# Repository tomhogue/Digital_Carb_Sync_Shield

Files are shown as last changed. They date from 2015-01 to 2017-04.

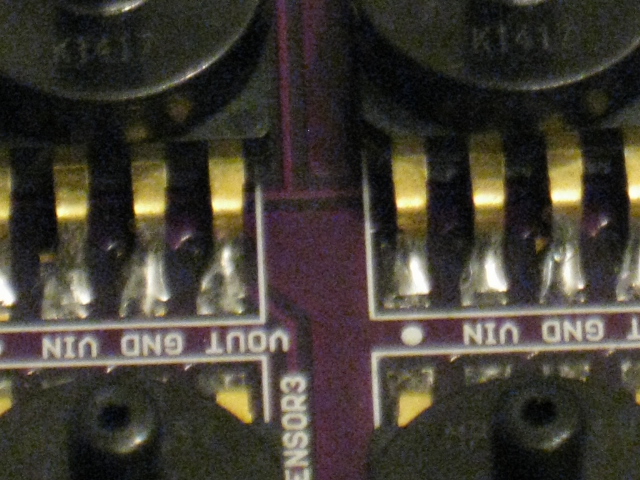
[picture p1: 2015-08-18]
CarbSync_CD_2015July/Pictures/hand solder results.JPG

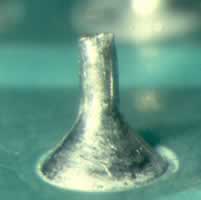
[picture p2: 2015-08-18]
CarbSync_CD_2015July/Pictures/good solder joint looks similar to this.jpg

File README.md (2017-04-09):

Digital Carb Sync Shield
========================

For the latest version and organization visit https://digitalcarbsync.com

Motorcycle carburetor synchronization. Analog sensors. LCD display. Easy to build. Wiki.

This repository is for the Digital Carb Sync Shield project. The shield is designed for the Arduino UNO R3
and other compatible boards.

The software is licensed under the MIT model.
The hardware is licensed using Open Hardware License.

The shield reads up to 6 vacuum pressure sensors on A0-5 and displays running peaks.

There is a calibration step to average the analog inputs. This is to compensate for build quality issues.

###Bill of Materials#

Some PCB boards may be available to GitHub collaborators.

Partial BOM sourced at Digi-Key. Shop around.

###More information and history at#

http://www.venturerider.org/forum/showthread.php?90191-New-digital-carb-sync-board

and its evolution from old auto parts

http://www.venturerider.org/forum/showthread.php?73158-Built-a-digital-carb-sync

and for Honda Valkyrie riders

http://www.valkyrieforum.com/bbs/index.php/topic,73795.0.html
http://www.valkyrieforum.com/bbs/index.php/topic,74909.0.html

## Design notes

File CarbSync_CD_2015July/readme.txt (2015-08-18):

Please read all the instructions in the CarbSync_Info folder before you begin.

There are useful pictures in the Pix folder.

The info folder includes the bill of materials, and helpful alternatives when ordering 
from the web.

The XLoader folder contains the MS-Windows program to load the software onto the board.
The software hex files are in the same folder.

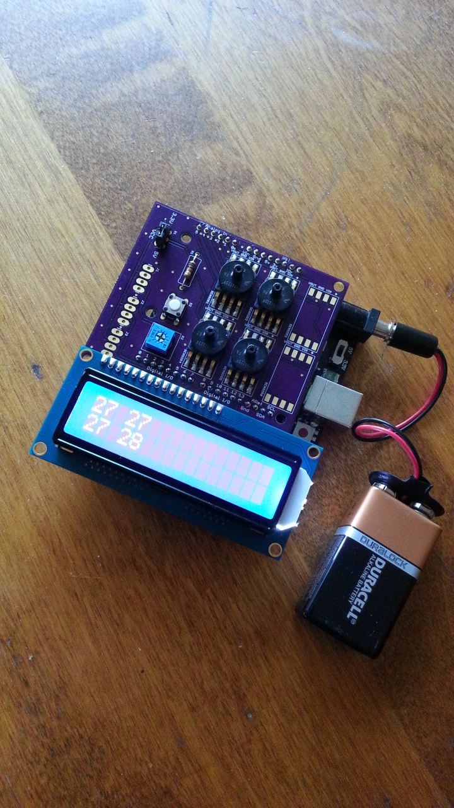
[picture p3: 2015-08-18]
CarbSync_CD_2015July/Pictures/powered up.jpg

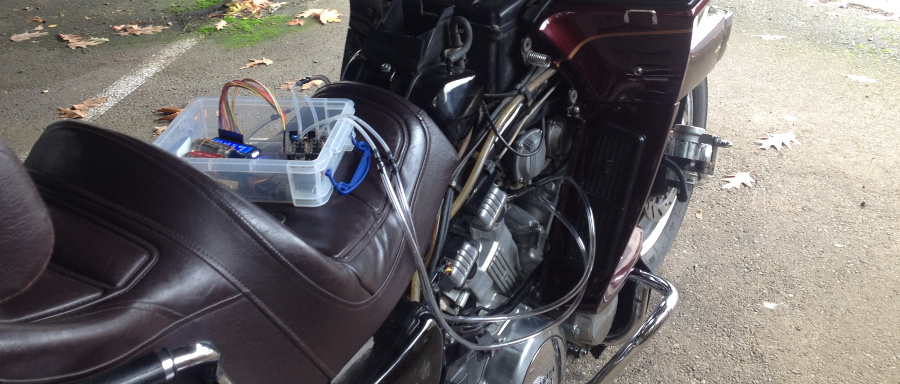
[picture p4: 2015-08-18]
CarbSync_CD_2015July/Pictures/in use 01.JPG

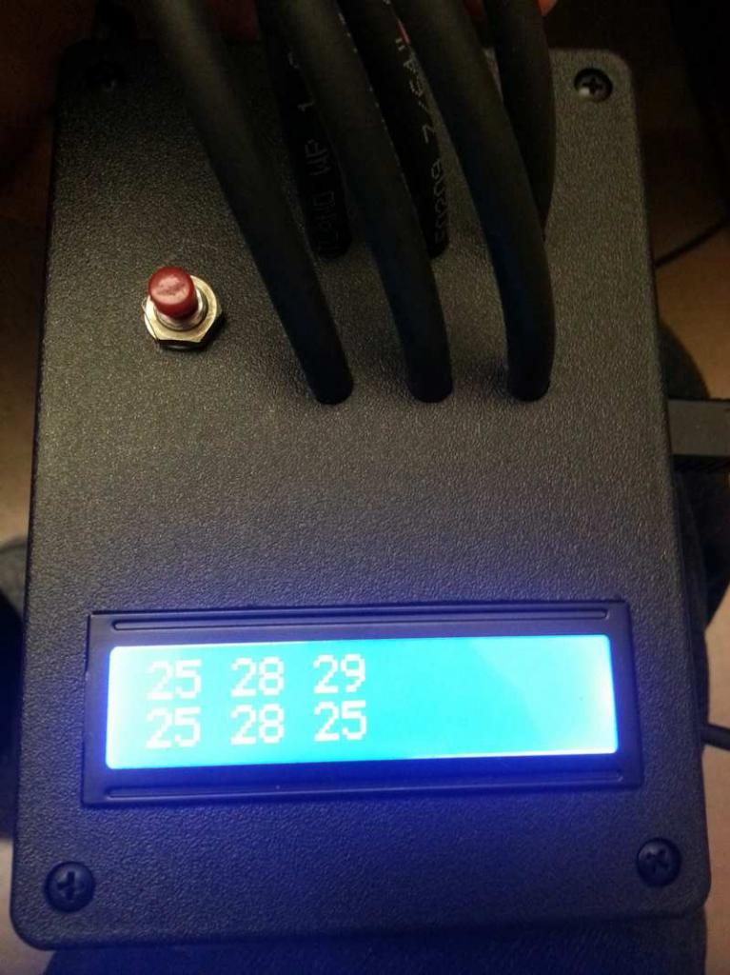
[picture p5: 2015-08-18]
CarbSync_CD_2015July/Pictures/a nice enclosure 2.jpg

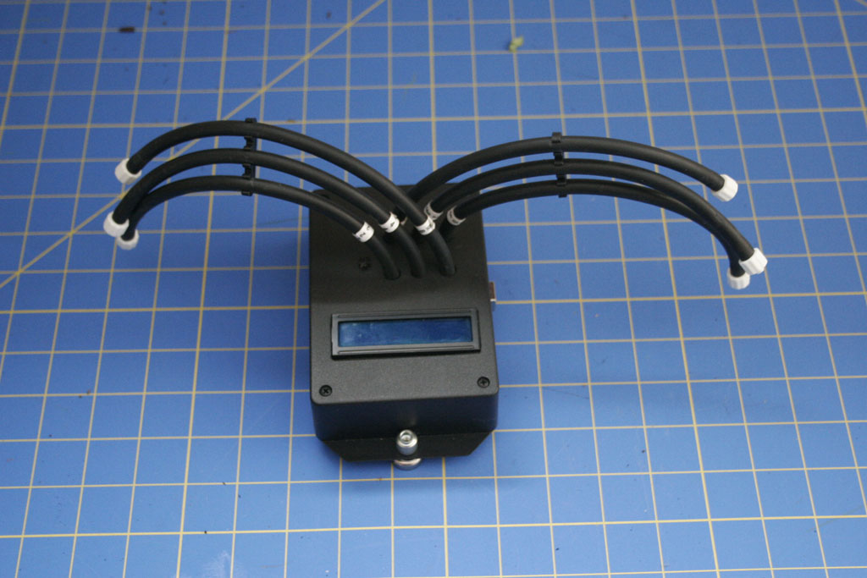
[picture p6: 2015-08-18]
CarbSync_CD_2015July/Pictures/a nice enclosure.jpg

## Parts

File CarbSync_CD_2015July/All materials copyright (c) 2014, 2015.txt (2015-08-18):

Copyright (c) Tom Hogue 2014, 2015

You may not duplicate, publish or distribute any material
without the express written consent of the copyright holder.

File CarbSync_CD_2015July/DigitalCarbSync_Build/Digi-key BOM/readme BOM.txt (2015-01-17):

Shop around for better prices on the Arduino, the LCD and sensors.

The LCD is a standard item and much cheaper elsewhere. Just look for a 16x2 text backlit LCD.
80mm x 36mm outline is usual. About 12mm thick. 16pin connection. 0.1" (2.54mm) pitch.

The sensors are sometimes available at a lower price.

The rest of the parts are fairly cheap and fit the board

You can find compatible clones on Amazon and Ebay for the Arduino UNO R3.

These BOMs can be uploaded at digikey.com to create an order.
The order can be edited.
There is a lot of info that is not applicable in the BOM files.

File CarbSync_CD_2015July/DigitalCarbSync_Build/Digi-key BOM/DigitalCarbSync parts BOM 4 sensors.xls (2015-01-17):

Digi-Key Part Number | Manufacturer | Manufacturer Part Number | Customer Reference | Quantity 1 | Quantity 2 | Quantity 3 | Mfg Std Lead Time | Description | Comments | RoHS Status | Lead Free Status | REACH Status
3362U-102LF-ND | BOURNS INC | 3362U-1-102LF | R2 | 1 | 0 | 0 | 12 Weeks | TRIMMER 1K OHM 0.5W PC PIN | Alternate Packaging Exists | RoHS Compliant | Lead free | Unaffected Jun-2014
SW400-ND | OMRON ELECTRONICS INC-EMC DIV | B3F-1000 | S2 | 1 | 0 | 0 | 11 Weeks | SWITCH TACTILE SPST-NO 0.05A 24V |  | RoHS Compliant | Lead free | N/A
CF14JT10K0CT-ND | STACKPOLE ELECTRONICS INC (VA) | CF14JT10K0 | R1 | 1 | 0 | 0 | 12 Weeks | RES 10K OHM 1/4W 5% CARBON FILM | Alternate Packaging Exists | RoHS Compliant | Lead free | Unaffected Jun-2014
S1012EC-40-ND | SULLINS CONNECTOR SOLUTIONS | PREC040SAAN-RC | UNO, LCD, S1, J1,J2,J3 | 2 | 0 | 0 | 2-4 Weeks | CONN HEADER .100" SNGL STR 40POS |  | RoHS Compliant | Lead free | Unaffected Dec-2013
3M9580-ND | 3M | 969102-0000-DA | OPTIONAL S1 | 1 | 0 | 0 | 8 Weeks | SHUNT JUMPER .1" BLACK GOLD |  | RoHS Compliant | Lead free | Not Available
MPXV6115VC6U-ND | FREESCALE SEMICONDUCTOR | MPXV6115VC6U | SENSORS 1,2,4,5 | 4 | 0 | 0 | 9 Weeks | SENSOR DIFF PRESS 2.2PSI MAX | Alternate Packaging Exists | RoHS Compliant | Lead free | Unaffected Dec-2011
NHD-0216XZ-FSW-GBW-ND | NEWHAVEN DISPLAY INTL | NHD-0216XZ-FSW-GBW | LCD | 1 | 0 | 0 | 14-16 Weeks | LCD MOD CHAR 2X16 TRANSFL |  | RoHS Compliant | Lead free | Unaffected Dec-2013
1050-1041-ND | MAGYC NOW LIMITED | A000073 | SHOP AROUND | 1 | 0 | 0 | 2-3 Weeks | ARDUINO UNO SMD REV3 |  | RoHS Compliant | Lead free | N/A

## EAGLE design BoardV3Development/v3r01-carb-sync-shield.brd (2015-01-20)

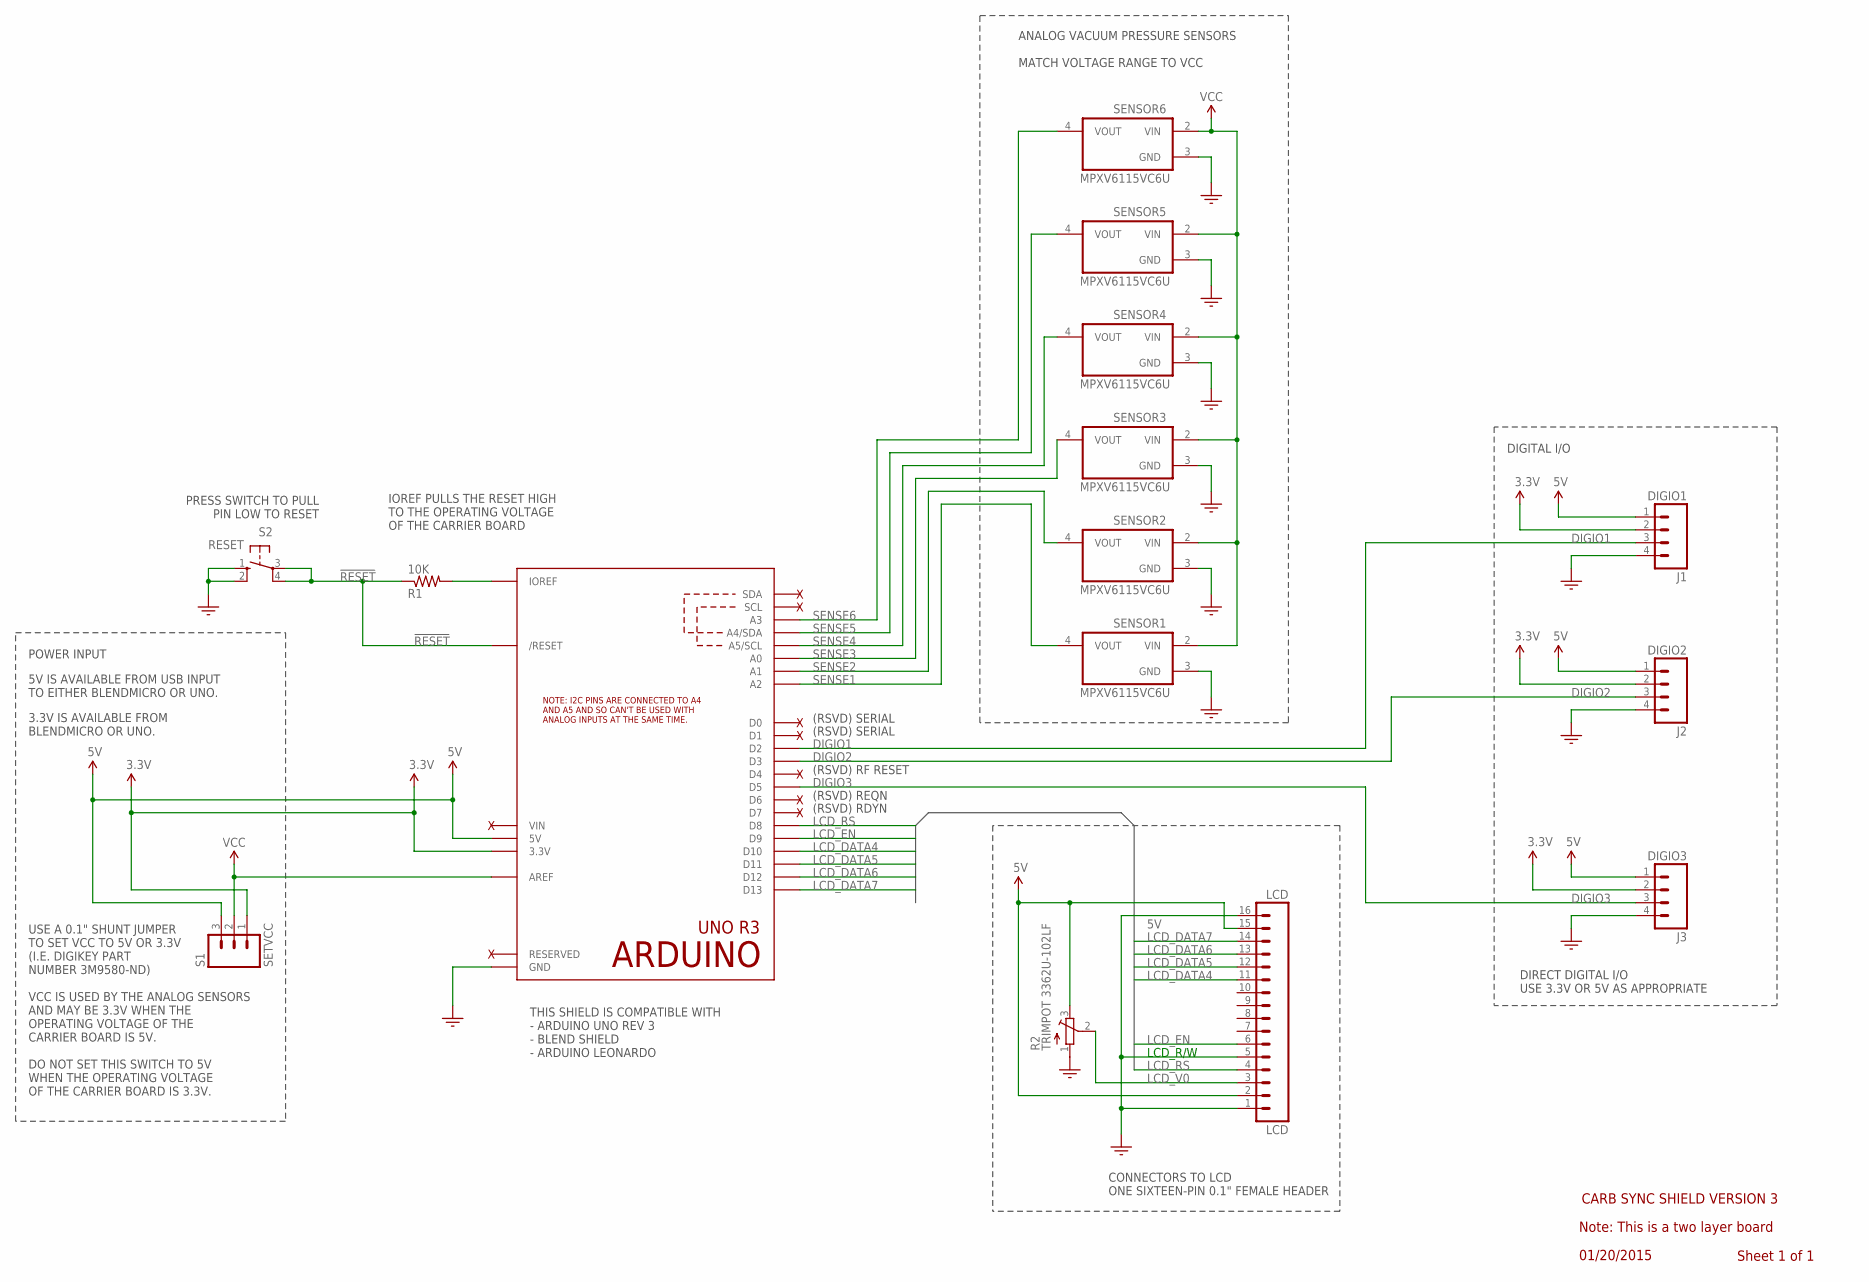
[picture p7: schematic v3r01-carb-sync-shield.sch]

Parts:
J1: DIGIO1; 1X04_LONGPADS
J2: DIGIO2; 1X04_LONGPADS
J3: DIGIO3; 1X04_LONGPADS
LCD: LCD; CARBSYNCSHIELD_LCD
R1: 10K; 0411/12
R2: TRIMPOT 3362U-102LF; TRIM-3386
S1: SETVCC; 1X03_LONGPADS
S2: RESET; B3F-10XX
SENSOR1, SENSOR2, SENSOR3, SENSOR4, SENSOR5, SENSOR6: MPXV6115VC6U; MPXV6115VC6U/T1-CASE482A
U$13: ARDUINO-UNO-R3; ARDUINO-UNO-R3-HOLES-NODIM

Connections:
3.3V: J1.2, J2.2, J3.2, S1.1, U$13.3V (3.3V)
5V: J1.1, J2.1, J3.1, LCD.2, LCD.15, R2.3 (E), S1.3, U$13.5V
!RESET: R1.1, S2.3, S2.4 (P1), U$13.RESET (/RESET)
DIGIO1: J1.3, U$13.D2
DIGIO2: J2.3, U$13.D3
DIGIO3: J3.3, U$13.D5
GND: J1.4, J2.4, J3.4, LCD.1, LCD.5, LCD.16, R2.1 (A), S2.1 (S), S2.2 (S1), SENSOR1.3 (GND), SENSOR2.3 (GND), SENSOR3.3 (GND), SENSOR4.3 (GND), SENSOR5.3 (GND), SENSOR6.3 (GND), U$13.GND, U$13.GND1 (GND), U$13.GND2 (GND)
IOREF: R1.2, U$13.IOREF
LCD_DATA4: LCD.11, U$13.D10
LCD_DATA5: LCD.12, U$13.D11
LCD_DATA6: LCD.13, U$13.D12
LCD_DATA7: LCD.14, U$13.D13
LCD_EN: LCD.6, U$13.D9
LCD_RS: LCD.4, U$13.D8
LCD_V0: LCD.3, R2.2 (S)
SENSE1: SENSOR1.4 (VOUT), U$13.A2
SENSE2: SENSOR2.4 (VOUT), U$13.A1
SENSE3: SENSOR3.4 (VOUT), U$13.A0
SENSE4: SENSOR4.4 (VOUT), U$13.A5 (A5/SCL)
SENSE5: SENSOR5.4 (VOUT), U$13.A4 (A4/SDA)
SENSE6: SENSOR6.4 (VOUT), U$13.A3
VCC: S1.2, SENSOR1.2 (VIN), SENSOR2.2 (VIN), SENSOR3.2 (VIN), SENSOR4.2 (VIN), SENSOR5.2 (VIN), SENSOR6.2 (VIN), U$13.AREF
VIN: U$13.VIN

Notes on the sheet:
ANALOG VACUUM PRESSURE SENSORS MATCH VOLTAGE RANGE TO VCC
PRESS SWITCH TO PULL PIN LOW TO RESET
CARB SYNC SHIELD VERSION 3
Sheet 1 of 1
01/20/2015
Note: This is a two layer board
CONNECTORS TO LCD ONE SIXTEEN-PIN 0.1" FEMALE HEADER
LCD_R/W
DIGITAL I/O
5V IS AVAILABLE FROM USB INPUT TO EITHER BLENDMICRO OR UNO.
3.3V IS AVAILABLE FROM BLENDMICRO OR UNO.
POWER INPUT
DIRECT DIGITAL I/O USE 3.3V OR 5V AS APPROPRIATE
THIS SHIELD IS COMPATIBLE WITH - ARDUINO UNO REV 3 - BLEND SHIELD - ARDUINO LEONARDO
(RSVD) REQN
(RSVD) RF RESET
(RSVD) RDYN
(RSVD) SERIAL
IOREF PULLS THE RESET HIGH TO THE OPERATING VOLTAGE OF THE CARRIER BOARD
USE A 0.1" SHUNT JUMPER TO SET VCC TO 5V OR 3.3V (I.E. DIGIKEY PART NUMBER 3M9580-ND) VCC IS USED BY THE ANALOG SENSORS AND MAY BE 3.3V WHEN THE OPERATING VOLTAGE OF THE CARRIER BOARD IS 5V. DO NOT SET THIS SWITCH TO 5V WHEN THE OPERATING VOLTAGE OF THE CARRIER BOARD IS 3.3V.

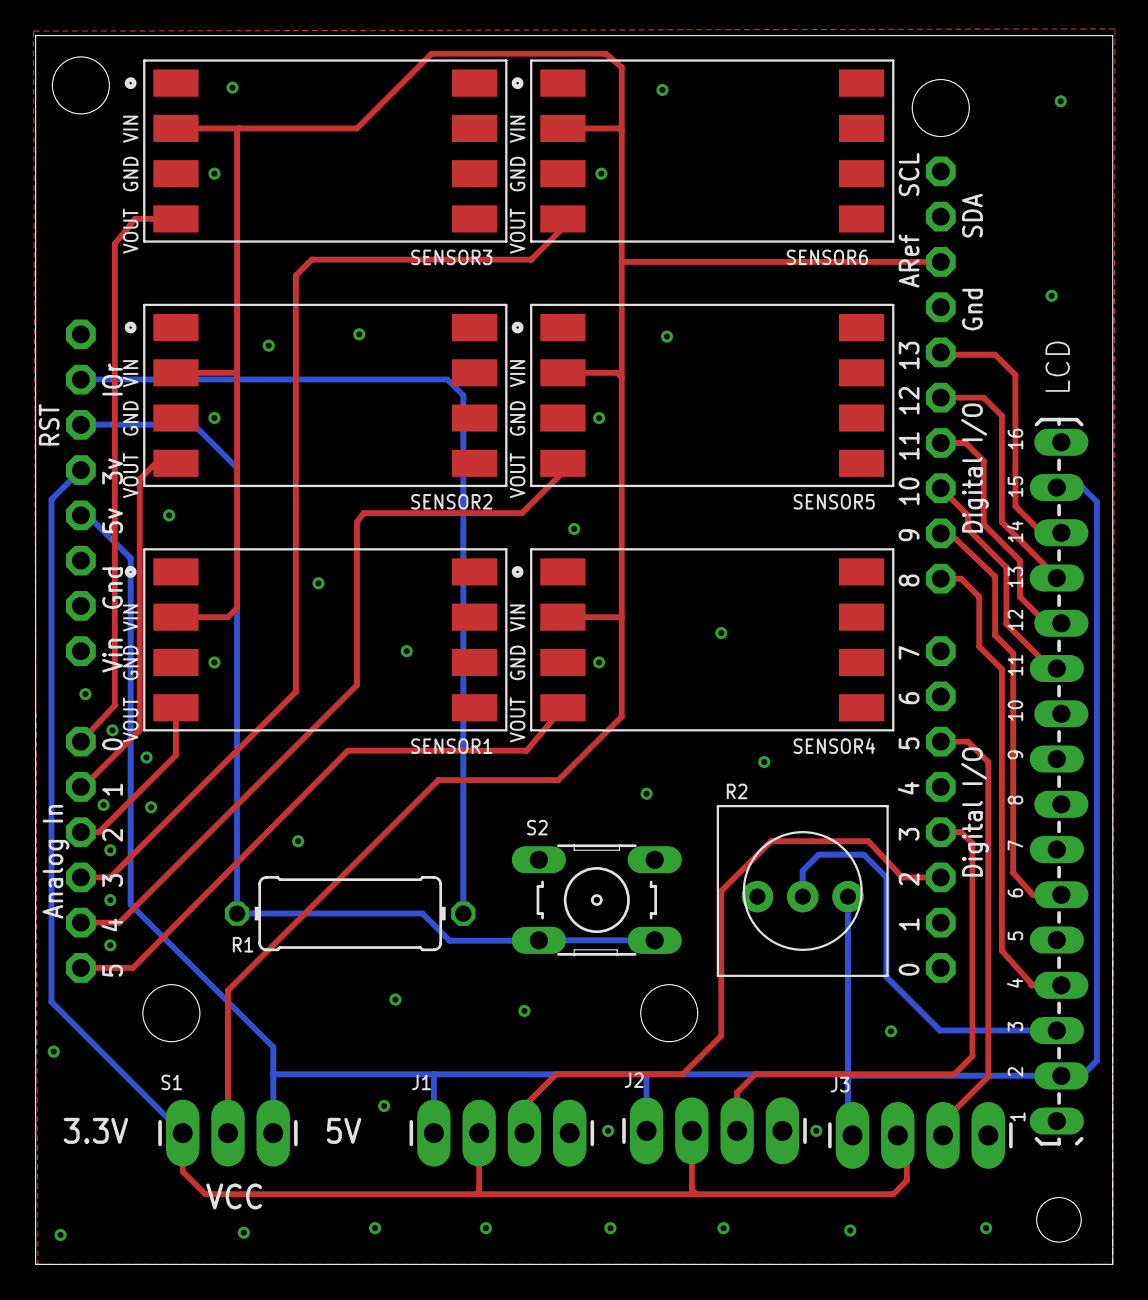
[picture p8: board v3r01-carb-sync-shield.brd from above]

Board: 2 copper layers, 60.5 x 69.0 mm, 15 parts (0 on the bottom side), 22 nets.

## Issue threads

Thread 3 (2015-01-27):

Use IOREF to power sensors

tomhogue, 2015-01-27:
The notion to make sensor voltage selected on the shield should be deprecated. It was an artifact of the (incorrect?) method to support a Red Bear Lab board. The sensors should be wired to IOREF. Remove the connection to AREF. The code has to change to remove setting AREF to EXTERNAL.

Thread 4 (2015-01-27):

Power to the LCD

tomhogue, 2015-01-27:
If the shield changes to run sensors from IOREF, what should be the correct way to power an LCD?

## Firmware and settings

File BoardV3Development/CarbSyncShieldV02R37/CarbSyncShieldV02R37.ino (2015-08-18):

/*
 Copyright (c) Tom Hogue 2015
 www.DigitalCarbSync.com

 For Arduino Uno R3
 Accepts 5-0v from 1 bar pressure sensors
 Creates arrays of values for all cylinders
 */


#include <PinChangeInt.h>

/* obsolete
// #define PIN 3
// the interrupt pin be careful with text substitution
// #define INTERRUPT 1
// the int associate with the pin per board
// Pin 3 is interrput 1 on the Uno
// Pin 3 is interrupt 0 on the Leonardo and probably the blendmicro
*/
 
 
const byte numReadingsMax = 80;
/* this should be maybe 5-150. Too large overflows RAM.
 readings x cylinders x 2bytes per integer = size in ram
 The higher the number,
 the more the readings will be smoothed, but the slower the output will
 respond to the input.  Using a constant rather than a normal variable let us
 use this value to determine the size of the readings array.
 */
const byte numCylindersMax = 6;
/* max is 6 on shield. Reduce to actual number of sensors
 or calibration may be off. This sets up array sizes
*/

int inputPin[] = {2, 5, 1, 4, 0, 3}; //this determines display locations
/*
 Shield v2 sensor# labels left to right top to bottom is 2,1,0,5,4,3
 usual inputPin 2,5,1,4,0,3
 maps sensors and pins to array and display
 set the input pin array to match shield
 but it is only used per numCylinders
 These can be rearranged if desired
 to change tube placements
 board builders may tie signal out to voltage in for blank sensor pads
 */

byte rpmPer;
/*  sparks per revolution is bike specific
 it defaults to 1 which is most common
 is saved in EEPROM
 future mods may make this adjustable
 or it will be deprecated
 */

int sensitivity = 337;
/*  how fine input is parsed.
 - Must be less than 999 to fit LCD.
 - Must be less that 255 to send serial bytes
 - 500 makes a convenient voltage ratio
 - 337 makes it 1/10th inch of mercury per point RECOMMENDED
 - 674 makes it 5/100ths inch of mercury per point too sensitive
 */

byte calibrationFlag = 1;
/* use the first readings pass to calibrate
 1 means do calibration plus 2
 2 means do inches of mercury and cylinder sensor location displays
 then sets to zero and does it no more
 a good shield with good sensors doesn't need to calibrate
 because it introduces small integer math rounding errors
 a shield with quirky soldering may need calibration
 a shield with inconsistent sensors may need calibration
 */

// user adjustments above these lines only - be careful
// ====================================================
// ====================================================

#include <LiquidCrystal.h>
// initialize the library with the numbers of the interface pins
LiquidCrystal lcd(8, 9, 10, 11, 12, 13);
// v2 shield = 8,9,10,11,12,13
// Sainsmart LCD keypad 8,9,4,5,6,7 for testing

#include <EEPROM.h>   // to save num cyl and sparks per etc

volatile unsigned long rpmCnt = 0;
volatile unsigned long rpmTot = 0;

int readings[numCylindersMax][numReadingsMax];   // the readings from the analog input
byte numReadings = numReadingsMax;              // allow this to change to vary smooth vs speed
byte numCylinders = numCylindersMax;           //
long total[numCylindersMax];                  // the running total
int average[numCylindersMax];                // the running average
int runPeak [numCylindersMax];              // running peak value
int calibrate [numCylindersMax];           // an adjustment for input voltage variance


// new attempt to smooth RPM
#define filterSamples   7              // filterSamples should  be an odd number, no smaller than 3
int sensSmoothArray1 [filterSamples];

const String msg16[] = {
"Original V2R37  ",
"DigitalCarbSync ",
"Cy1 Cy3 Cy5 RPM ",
"Cy2 Cy4 Cy6 nnn ",
"Cylinders = ",
"Calibrate = ",
};
const String msg3[] = {
"Cy1",
"Cy2",
"Cy3",
"Cy4",
"Cy5",
"Cy6",
"RPM",
"nnn"
};


void setup()
{
  analogReference(EXTERNAL);   // MUST CALL BEFORE ANALOGREAD !!!!!!
  //Serial.begin(9600);  // for debugging. Serial collides with noInterrupts - duh.
  //Serial.println("begin");
  //delay(3000);

  // initialize LCD
  // set up the LCD's number of columns and rows. Might want 4 rows some day
  //lcd.begin(20, 4);
  lcd.begin(16, 2);
  // initialize LCD
  //  lcd.init();
  //  lcd.backlight();
  //  Serial.println("lcd");
  //  delay(1000);
 // cntRA.clear();

  // new timer code
  cli(); //stop interrupts
  //set timer1 interrupt at 1Hz
  TCCR1A = 0; // set entire TCCR1A register to 0
  TCCR1B = 0; // same for TCCR1B
  TCNT1  = 0; //initialize counter value to 0
  // set compare match register for 1 second increments
  OCR1A = 31248; // 1 sec = (16*10^6) / (1*1024) - 1 (must be <65536) 31248==2 secs
  // turn on CTC mode
  TCCR1B |= (1 << WGM12);
  // Set CS10 and CS12 bits for 1024 prescaler
  TCCR1B |= (1 << CS12) | (1 << CS10);
  // enable timer compare interrupt
  TIMSK1 |= (1 << OCIE1A);
  sei(); //allow interrupts

  // end new timer code

  //
  // attach innterupt code
  pinMode(A2, INPUT);     //set the pin to input
  
  /* obsolete using UNO interrupt port
  // digitalWrite(PIN, HIGH); //not sure about this
  // attachInterrupt(INTERRUPT,rpmInt,FALLING);
  //
  */
  
  // alternative interrupt to read off sensor EXPERIMENTAL
  PCintPort::attachInterrupt(A2, rpmInt, FALLING); // for non hardware interrupt pins
  //
  // sparks per revolution. bike specific.
  //Serial.println("atc");
  //  delay(1000);
 
  rpmPer = EEPROM.read(1);
  //  Serial.println(rpmPer);
  //  delay(1000);
  if (rpmPer < 1 || rpmPer > 2) {
    rpmPer = 1; // if first time setting pick 1. Allow change to 2 someday.
    //    Serial.println("y");
    EEPROM.write(1, rpmPer);
  }

  // initialize all the readings to 0:
  for (byte thisCylinder = 0; thisCylinder < numCylinders; thisCylinder++)
  {

    total[thisCylinder] = 0;
    average[thisCylinder] = 0;
    runPeak[thisCylinder] = 0;
    calibrate[thisCylinder] = 0;
    for (byte thisReading = 0; thisReading < numReadings; thisReading++)
    {
      readings [thisCylinder][thisReading] = 0;
    }
  }
}

void loop() {
  loadRA();
  switch (calibrationFlag)
  {
    case 0:
      for (byte thisCylinder = 0; thisCylinder < numCylinders; thisCylinder++)
      {
        // calculate the peak
        for (int thisPeak = 0; thisPeak < numReadings; thisPeak++)
        {
          runPeak[thisCylinder] = max(runPeak[thisCylinder], readings[thisCylinder][thisPeak]);
        }
      }
      display();
      break;

    case 1:
      runCali();
    case 2:         //should drop through
      calcInhg();
      pinLocs();
      calibrationFlag = 0;

  }
  /* set a short delay between
   readings to add stability
   set to approx 1ms when running live
   */
  delay (1);
}

void loadRA() {
  /* for each reading read all cylinders then increment
   to keep coordination close to right in theory
   we are looping with index pre-set in setup, then incremented and reset here
   */
  for (byte index = 0; index < numReadings; index++)
  {
    for (byte thisCylinder = 0; thisCylinder < numCylinders; thisCylinder++)
    {

      // subtract the last reading
      // or switch logic to use runingAverage which uses real number arrays not integer
      total[thisCylinder] = total[thisCylinder]  - readings[thisCylinder][index];
      /* read from the sensor. As vacuum increases MAP sensor output signal voltage drops
       so use map command to reverse output so that
       more vacuum == lower voltage == higher data points
       */
      readings[thisCylinder][index] = map(analogRead(inputPin[thisCylinder]), 0, 1023, sensitivity, 0) + calibrate[thisCylinder];
      // add the reading to the total

      total[thisCylinder] = total[thisCylinder]  + readings[thisCylinder] [index];

      // calculate the average: overwrites previous until last reading
      // this could use some improvement and efficiency
      if (calibrationFlag > 0) average[thisCylinder]  = total[thisCylinder]  / (index + 1);
    }
    delay(1);
  }
}
void display() {
  //Serial.println("display");
  //delay(2000);
  // this all could use some efficiency

  String outString;
  String outString2;
  String outNum;
  byte dispCylinder = 0;

 /* obsolete
  //  unsigned long rpmTime = millis();   // if these are moved below the first time through is error
  //  rpmCnt=0;                // but we could maybe get rid of the delay and let
  // the readings cycle be our rpm period. Remember to make rpmTime global.
  */

  delay(500);
  
  int smoothData1 = digitalSmooth(rpmTot, sensSmoothArray1);  // every sensor you use with digitalSmooth needs its own array
  float rpmFloat=smoothData1;
  rpmFloat *= 60;

/*
  //* For floatiing point math
  // mult revs by the conversion to mins before dividing by elapsed time
  // then trim to integer
  // Both time and count are inflated when multiple sparks per rev
   //
  //cntRA.addValue(rpmTot);  // count per 2 secs
  //float rpmFloat=cntRA.getAverage();
  // float rpmFloat = rpmTot;
  //rpmFloat *= 60.0;
  //rpmFloat /= 2.0;
  //rpmFloat *= 30.0; // slightly more efficient
  //rpmFloat *= 2; // TEST vacuum pulse rpm could set above to 60
 */
  
  
  if (rpmPer > 1) rpmFloat /= float(rpmPer); // if multiple sparks per revolution

  lcd.clear();
  outString = msg16[2];
  outString2 = msg16[3];
  switch (numCylinders) {
    case 6:
      outNum = "";
      outNum += runPeak[5];
      outString2.replace(msg3[5], outNum);
    case 5:
      outString2.replace(msg3[5], ""); // if still there
      outNum = "";
      outNum += runPeak[4];
      outString.replace(msg3[4], outNum);
    case 4:
      outString2.replace(msg3[5], ""); // if still there
      outString.replace(msg3[4], ""); // if still there
      outNum = "";
      outNum += runPeak[3];
      outString2.replace(msg3[3], outNum);
    case 3:
      outString2.replace(msg3[5], ""); // if still there
      outString.replace(msg3[4], ""); // if still there
      outString2.replace(msg3[3], ""); // if still there
      outNum = "";
      outNum += runPeak[2];
      outString.replace(msg3[2], outNum);
    case 2:
      outString2.replace(msg3[5], ""); // if still there
      outString.replace(msg3[4], ""); // if still there
      outString2.replace(msg3[3], ""); // if still there
      outString.replace(msg3[2], ""); // if still there
      outNum = "";
      outNum += runPeak[1];
      outString2.replace(msg3[1], outNum);
    default:
      outNum = "";
      outNum += runPeak[0];
      outString.replace(msg3[0], outNum);
      // load rpm display here
      if (rpmTot > 0) {
        char buffer[10];
        outNum = "";
        outNum += dtostrf(rpmFloat, 3, 0, buffer);
        outString2.replace(msg3[7], outNum);
      }
      else {
        outString.replace(msg3[6], "   "); // blank out if not in use
        outString2.replace(msg3[7], "   "); // but hold position
      }
      lcd.setCursor(0, 0);
      lcd.print (outString);
      lcd.setCursor(0, 1);
      lcd.print (outString2);
  }


  // delay (500);

  // reset all the readings to 0:
  for (dispCylinder = 0; dispCylinder < numCylinders; dispCylinder++)
  {
    runPeak[dispCylinder] = 0;  // must reset this. others are kept running for now
    /*   total[dispCylinder] = 0;
     average[dispCylinder] = 0;
     for (int dispReading = 0; dispReading < numReadings; dispReading++)
     { readings [dispCylinder][dispReading] = 0;
     }
     */
  }
}

void runCali() {
  //Serial.println("runCali");
  String outString;
  byte calibrateCylinder;             //
  int calibrationMean;                 // the input adjustment added to each reading

  calibrationMean = 0;
  for (calibrateCylinder = 0; calibrateCylinder < numCylinders; calibrateCylinder++)
  {
    calibrationMean += average[calibrateCylinder];
  }
  calibrationMean /= numCylinders;
  for (calibrateCylinder = 0; calibrateCylinder < numCylinders; calibrateCylinder++)
  {
    calibrate [calibrateCylinder] = calibrationMean - average [calibrateCylinder];
  }

  lcd.clear();
  lcd.setCursor(0, 0);
  outString = msg16[0];
  lcd.print (outString);
  lcd.setCursor(0, 1);
  outString = msg16[1];
  lcd.print (outString);
  delay (2000);
  lcd.clear();
  lcd.setCursor(0, 0);
  outString = msg16[4];  // this really should be number of sensors
  outString += numCylinders;
  lcd.print (outString);
  lcd.setCursor(0, 1);
  outString = msg16[5];
  outString += calibrationMean; // average of the averages
  lcd.print (outString);
  delay (1000);

  lcd.clear();
  lcd.setCursor(0, 0);
  outString = "";
  outString += calibrate[0];
  outString += " ";
  outString += calibrate[2];
  outString += " ";
  outString += calibrate[4];
  lcd.print (outString);
  lcd.setCursor(0, 1);
  outString = "";
  outString += calibrate[1];
  outString += " ";
  outString += calibrate[3];
  outString += " ";
  outString += calibrate[5];
  lcd.print (outString);
  delay (1000);
}

void pinLocs() {
  // show where cylinders are (add pin data later)
  String outString = msg16[2];
  lcd.clear();
  lcd.setCursor(0, 0);
  lcd.print (outString);
  outString = msg16[3];
  lcd.setCursor(0, 1);
  lcd.print (outString);
  delay (1000);
}

void calcInhg() {
  //Serial.println ("calcInhg");
  // calc and display 1 point = x inches of mercury here
  lcd.clear();
  lcd.setCursor(0, 0);
  float inchesHg = 0;
  inchesHg = 33.9634 / (float)sensitivity; // sensor range 115 kPa in inHg / sensitivity
  String outString = "1pt ==";
  char buffer[10];
  String inHgstr = dtostrf(inchesHg, 7, 2, buffer);
  outString += (inHgstr);
  lcd.print (outString);
  lcd.setCursor(0, 1);
  outString = " inches Hg";
  lcd.print (outString);
  delay (1000);
}

int digitalSmooth(int rawIn, int *sensSmoothArray){     // "int *sensSmoothArray" passes an array to the function - the asterisk indicates the array name is a pointer
  int j, k, temp, top, bottom;
  long total;
  static int i;
 // static int raw[filterSamples];
  static int sorted[filterSamples];
  boolean done;

  i = (i + 1) % filterSamples;    // increment counter and roll over if necc. -  % (modulo operator) rolls over variable
  sensSmoothArray[i] = rawIn;                 // input new data into the oldest slot

  // Serial.print("raw = ");

  for (j=0; j<filterSamples; j++){     // transfer data array into anther array for sorting and averaging
    sorted[j] = sensSmoothArray[j];
  }

  done = 0;                // flag to know when we're done sorting              
  while(done != 1){        // simple swap sort, sorts numbers from lowest to highest
    done = 1;
    for (j = 0; j < (filterSamples - 1); j++){
      if (sorted[j] > sorted[j + 1]){     // numbers are out of order - swap
        temp = sorted[j + 1];
        sorted [j+1] =  sorted[j] ;
        sorted [j] = temp;
        done = 0;
      }
    }
  }

/*
  for (j = 0; j < (filterSamples); j++){    // print the array to debug
    Serial.print(sorted[j]); 
    Serial.print("   "); 
  }
  Serial.println();
*/

  // throw out top and bottom 15% of samples - limit to throw out at least one from top and bottom
  bottom = max(((filterSamples * 15)  / 100), 1); 
  top = min((((filterSamples * 85) / 100) + 1  ), (filterSamples - 1));   // the + 1 is to make up for asymmetry caused by integer rounding
  k = 0;
  total = 0;
  for ( j = bottom; j< top; j++){
    total += sorted[j];  // total remaining indices
    k++; 
    // Serial.print(sorted[j]); 
    // Serial.print("   "); 
  }

//  Serial.println();
//  Serial.print("average = ");
//  Serial.println(total/k);
  return total / k;    // divide by number of samples
}

void rpmInt() {
  //interrupt commands here
  rpmCnt++;
}

ISR(TIMER1_COMPA_vect) {
  //interrupt commands here
  rpmTot = rpmCnt;
  rpmCnt = 0;
}

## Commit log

2014-11-30 First commit
    This is the first publication of the software for the Digital Carb Sync
    Shield software for Arduino.
2014-11-30 add V2 board and schematic files
    The V2 board and schematic files.
    [v2-carb-sync-shield.brd, v2-carb-sync-shield.sch]
2014-11-30 V2 gerber files
    [v2-carb-sync-shield-drills.xln]
2014-11-30 Bill of materials
    Partial BOM sourced at Digi-Key. Shop around.
    Also requires 16x2 LCD such as this standard LCD from Adafruit. NOTE:
    This LCD comes with a header strip which reduces the need for headers on
    the BOM. It also comes with a trimmer pot the board is NOT designed for.
    https://www.adafruit.com/products/181
    [Digi-key BOM.xls]
2015-01-17 Update BOM
    Updates to the bill of materials files
    [Carb Sync parts BOM 4 sensors.xls, Carb Sync parts BOM 6 sensors.xls, Digi-key BOM.xls]
2015-01-20 Final V2 and start V3 development
    This changes closes out V2 and initiates V3
    [Carb Sync parts BOM 4 sensors.xls, Carb Sync parts BOM 6 sensors.xls, v2-carb-sync-shield.brd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]
2015-01-20 change names and labels to v3
    [v3-carb-sync-shield.brd, v3-carb-sync-shield.sch]
2015-01-24 version and revision labels
    add v3r01 to board and schematic files
    [v3r01-carb-sync-shield.brd, v3r01-carb-sync-shield.sch]
2015-03-08 remove old board files temp
    Remove old board files. Will post V3 soon.
    [v2-carb-sync-shield.brd, v2-carb-sync-shield.sch, v3r01-carb-sync-shield.brd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]
2015-04-19 replace v2
    replace v2 pending more v3 work
    [v3r01-carb-sync-shield.brd, v3r01-carb-sync-shield.sch]
2015-08-18 Add CD and RPM test V02R37
    R37 includeds RPM code
    [DigitalCarbSync parts BOM 4 sensors.xls, DigitalCarbSync parts BOM 6 sensors.xls]

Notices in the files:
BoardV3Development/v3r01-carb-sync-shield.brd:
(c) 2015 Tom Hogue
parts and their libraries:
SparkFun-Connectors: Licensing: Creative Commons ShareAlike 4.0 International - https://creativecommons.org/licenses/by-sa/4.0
